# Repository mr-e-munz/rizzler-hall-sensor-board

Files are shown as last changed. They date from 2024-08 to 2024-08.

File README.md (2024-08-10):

# Eru's Rizzler Hall Sensor Board
## Design Overview
 - This is an alarm system using a hall effect sensor to detect when the door opens, and then create a sound.
 - There will be a module installed in the door to detect when the door is opened or closed.
 - It will be a BLE module which will broadcast the door state in its advertising manufacturer data
 - There will be a Raspberry Pi that listens to the manufacturer data, and will turn a buzzer on when the door is open, and off when it is closed.

## Design Requirements
 - Battery powered
 - LiSO-Cl2
 - Nominally use Tadiran AA-size SL-360 battery (3.6V) - see: https://tadiranbatteries.de/wp-content/uploads/2023/02/SL-360.pdf
 - Minimum time between battery changes = 2 years.
 - Raspbery Pi zero case - Core SKU: CE06235 - see: https://core-electronics.com.au/slim-case-for-raspberry-pi-zero.html
 - Raspberry Pi Zero W - Core SKU: CE04754 - see: https://core-electronics.com.au/raspberry-pi-zero-w-wireless.html

## Components
 - use TCS40DLR for hall effect sensor
 - use RF Star RF-BM-ND04C for BLE SoC module - see: https://www.szrfstar.com/product/BLE_Nordic_nRF52810-en.html

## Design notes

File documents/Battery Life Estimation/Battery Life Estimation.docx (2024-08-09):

# Battery Life Estimation

# Purpose

This calculation derives the expected battery life for the EK No Trespasser Door Alarm.

# System Overview

- This is an alarm system using a hal- effect sensor to detect when the door opens, and then create a sound.
- There will be a module installed in the door to detect when the door is opened or closed.
- It will be a BLE module which will broadcast the door state in its advertising manufacturer data
- There will be a Raspberry Pi that listens to the manufacturer data, and will turn a buzzer on when the door is open, and off when it is closed.

# Design Basis

- Battery powered
- LiSO-Cl2
- Nominally use Tadiran AA-size SL-360 battery (3.6V) - see: https://tadiranbatteries.de/wp-content/uploads/2023/02/SL-360.pdf
- Minimum time between battery changes = 2 years.
- use TCS40DLR for hall effect sensor
- use BT832AF for BLE SoC

# Calculation Approach

Given a target battery life, one can derive an average current draw. Subtracting from this value, the current consumption of the hall-effect sensor, one can estimate the permissible average current draw of the BLE SoC. Based on this average current draw, one can determine a suitable advertising rate.

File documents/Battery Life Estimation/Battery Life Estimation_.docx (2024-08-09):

# Battery Life Estimation

# 1 Purpose

This calculation derives the expected battery life for the EK No Trespasser Door Alarm.

# 2 System Overview

- This is an alarm system using a hall-effect sensor to detect when the door opens, and then create a sound.
- There will be a module installed in the door to detect when the door is opened or closed.
- It will be a BLE module which will broadcast the door state in its advertising manufacturer data
- There will be a Raspberry Pi that listens to the manufacturer data, and will turn a buzzer on when the door is open, and off when it is closed.

# 3 Design Basis

- Battery powered
- LiSO-Cl2
- Nominally use Tadiran AA-size SL-360 battery (3.6V, 1.9 Ah @ 20µA) - see: https://tadiranbatteries.de/wp-content/uploads/2023/02/SL-360.pdf
- Minimum time between battery changes = 2 years.
- use TCS40DLR for hall effect sensor
- use BT832AF for BLE SoC

# 4 Calculation Approach

Given a target battery life, one can derive an average current draw. Subtracting from this value, the current consumption of the hall-effect sensor, one can estimate the permissible average current draw of the BLE SoC. Based on this average current draw, one can determine a suitable advertising rate.

# 5 Calculation

## 5.1 Permissible Current Draw

Battery capacity | 1.9 | Ah
| 1900000 | µAh
Target life | 2 | years
| 17520 | hours
So permissible current draw | 108 | µA

## 5.2 Hall-effect Sensor Current Draw

From the data sheet, we can see at the operating voltage of 3.6V, the coincident average current draw will be 14µA.

## 5.3 Microprocessor Current Draw

This diagram shows how much power the nRF52832 uses at a battery voltage of 3.6V and an advertising period of 500 ms.

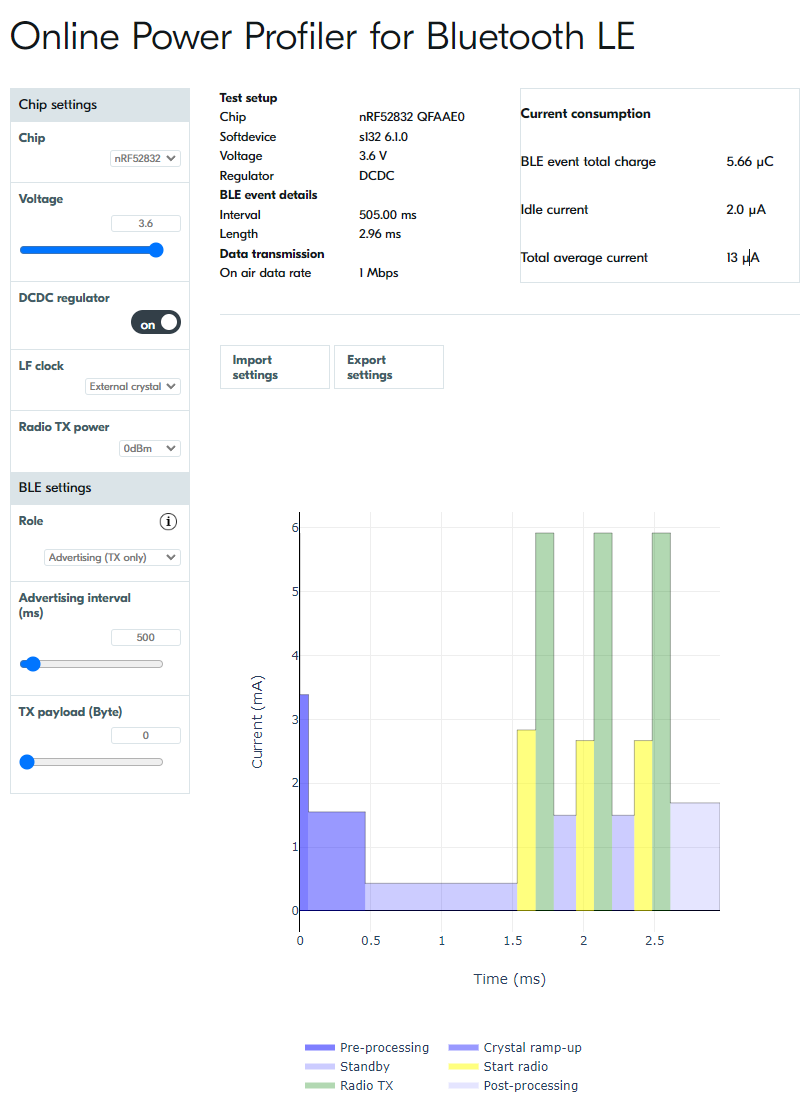
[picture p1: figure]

From the diagram, we can see that the average current consumption is 13uA.

## 5.4 Total Current Draw

From the calculation in sections 5.2 and 5.3, we can see that the total estimated current draw is 27uA. Based on a battery capacity of 1.9 Ah, this gives a total estimated runtime of 70,370 hours, which is approximately 8 years.

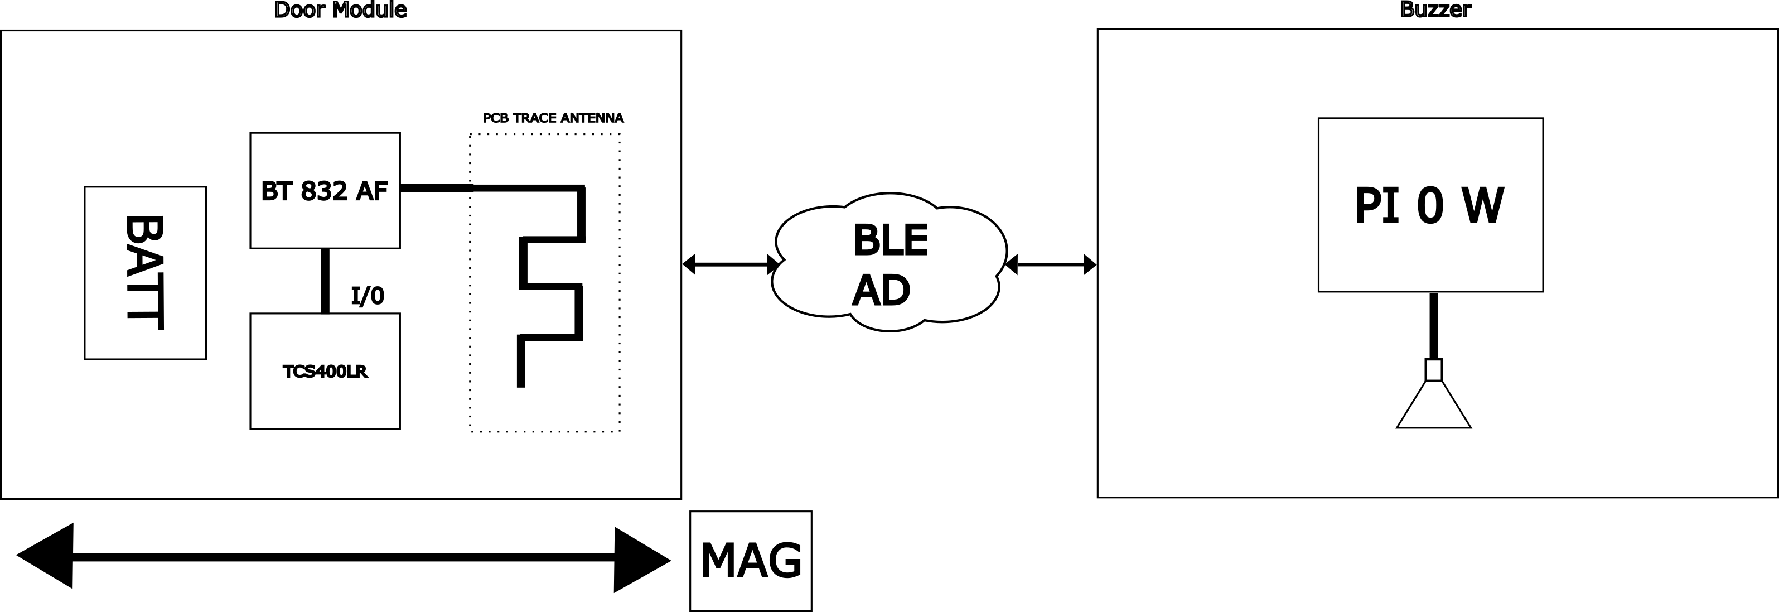
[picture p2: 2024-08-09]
documents/hw-block-diag.png

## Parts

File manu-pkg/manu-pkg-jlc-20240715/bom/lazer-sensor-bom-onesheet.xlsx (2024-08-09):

Comment | Designator | Footprint | JLCPCB Part #（optional）
C0805C474K3RACTU | C3 | FP-C0805C-DN-MFG | C2167558
100nF | C5 | CAPC0603X03L_C | C76939
GRM188R61C475KAAJD | C7 | FP-GRM188-0_15-MFG | C86016
CONN-TC2030 | J1 | TC2030-IDC-PLUG-OF-NAILS-TIGHT
1043P | J2 | FP-1043P-MFG | C3029535
XL-1606UOC | LED1 | LED-RA-1606 | C965861
XL-1606SURC | LED2 | LED-RA-1606 | C965860
NTZD3154NT1G | Q1 | ONSC-SOT-563-6-463A-01_V | C145189
RC0402FR-07100KL | R3, R5 | RESC1005X40X25ML05T10 | C60491
AC0402JR-0750RL | R4, R6 | FP-AC0402-IPC_C | C227387
TCS40DLR | U1 | SOT95P245X80-3N | C146312
RF-BM-ND04C | U2 | RF-BM-ND04 | C5441196

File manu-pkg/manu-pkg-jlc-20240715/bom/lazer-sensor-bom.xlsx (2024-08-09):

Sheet: jlc
Comment | Designator | Footprint | JLCPCB Part #（optional）
C0805C474K3RACTU | C3 | FP-C0805C-DN-MFG | C2167558
100nF | C5 | CAPC0603X03L_C | C76939
GRM188R61C475KAAJD | C7 | FP-GRM188-0_15-MFG | C86016
CONN-TC2030 | J1 | TC2030-IDC-PLUG-OF-NAILS-TIGHT
1043P | J2 | FP-1043P-MFG | C3029535
XL-1606UOC | LED1 | LED-RA-1606 | C965861
XL-1606SURC | LED2 | LED-RA-1606 | C965860
NTZD3154NT1G | Q1 | ONSC-SOT-563-6-463A-01_V | C145189
RC0402FR-07100KL | R3, R5 | RESC1005X40X25ML05T10 | C60491
AC0402JR-0750RL | R4, R6 | FP-AC0402-IPC_C | C227387
TCS40DLR | U1 | SOT95P245X80-3N | C146312
RF-BM-ND04C | U2 | RF-BM-ND04 | C5441196

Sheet: raw
MPN | Comment | Description | Designator | Footprint | LibRef | Quantity | JLC | JLC Part
C0805C474K3RACTU | C0805C474K3RACTU | CAP CER 0.47UF 25V X7R 0805 | C3 | FP-C0805C-DN-MFG | CMP-1036-04645-2 | 1 | JLC (https://jlcpcb.com/parts/componentSearch?searchTxt=) | C2167558
GRM033R61E104KE14D | 100nF | Capacitor, X5R, ±10% | C5 | CAPC0603X03L_C | C0201-100n | 1 | JLC (https://jlcpcb.com/parts/componentSearch?searchTxt=) | C76939
GRM188R61C475KAAJD | GRM188R61C475KAAJD | CAP CER 4.7UF 16V X5R 0603 | C7 | FP-GRM188-0_15-MFG | CMP-06035-062935-2 | 1 | JLC | C86016
 | CONN-TC2030 | TC2030 PLUG-OF-NAILS CABLE | J1 | TC2030-IDC-PLUG-OF-NAILS-TIGHT | CONN-TC2030 | 1 | JLC
1043P | 1043P | BATT HOLDER 18650 1 CELL PC PIN | J2 | FP-1043P-MFG | CMP-19636-000034-1 | 1 | JLC | C3029535
XL-1606UOC | XL-1606UOC | Orange LED 90° mount | LED1 | LED-RA-1606 | LED-ORANGE-RA | 1 | JLC | C965861
XL-1606SURC | XL-1606SURC | Red LED 90° mount | LED2 | LED-RA-1606 | LED-RED-RA | 1 | JLC | C965860
NTZD3154NT1G | NTZD3154NT1G | Small Signal MOSFET, 20 V, 540 mA, Dual N-Channel, 6-Pin SOT-563, Pb-Free, Tape and Reel | Q1 | ONSC-SOT-563-6-463A-01_V | CMP-1058-00829-1 | 1 | JLC | C145189
RC0402FR-07100KL | RC0402FR-07100KL |  | R3, R5 | RESC1005X40X25ML05T10 | CMP-2002-07343-1 | 2 | JLC | C60491
AC0402JR-0750RL | AC0402JR-0750RL | RES 50Ω ±5% 0.063W 0402 | R4, R6 | FP-AC0402-IPC_C | CMP-2002-01779-2 | 2 | JLC | C227387
TCS40DLR | TCS40DLR | Digital-Output Magnetic Sensor (Hall IC). Open drain. | U1 | SOT95P245X80-3N | IC-HALL-TCS40DLR | 1 | JLC | C146312
RF-BM-ND04C | RF-BM-ND04C | nRF52810-based Bluetooth 5.0 Low Energy module with internal 32 MHz and 32.768 kHz crystals. | U2 | RF-BM-ND04 | RF-BM-ND04C | 1 | JLC | C5441196

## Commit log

2024-08-09 tidy up
    [lazer-sensor-for-trespassers.PrjPcb, lazer-sensor-for-trespassers.SchDoc, rizzler-hall-sensor-board.PcbLib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]
2024-08-09 more tidy up
    [lazer-sensor-for-trespassers.PrjPcb, rizzler-hall-sensor-board.PrjPcb]
